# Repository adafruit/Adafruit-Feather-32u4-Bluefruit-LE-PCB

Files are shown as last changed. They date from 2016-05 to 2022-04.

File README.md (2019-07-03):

## Adafruit Feather 32u4 Bluefruit LE PCB

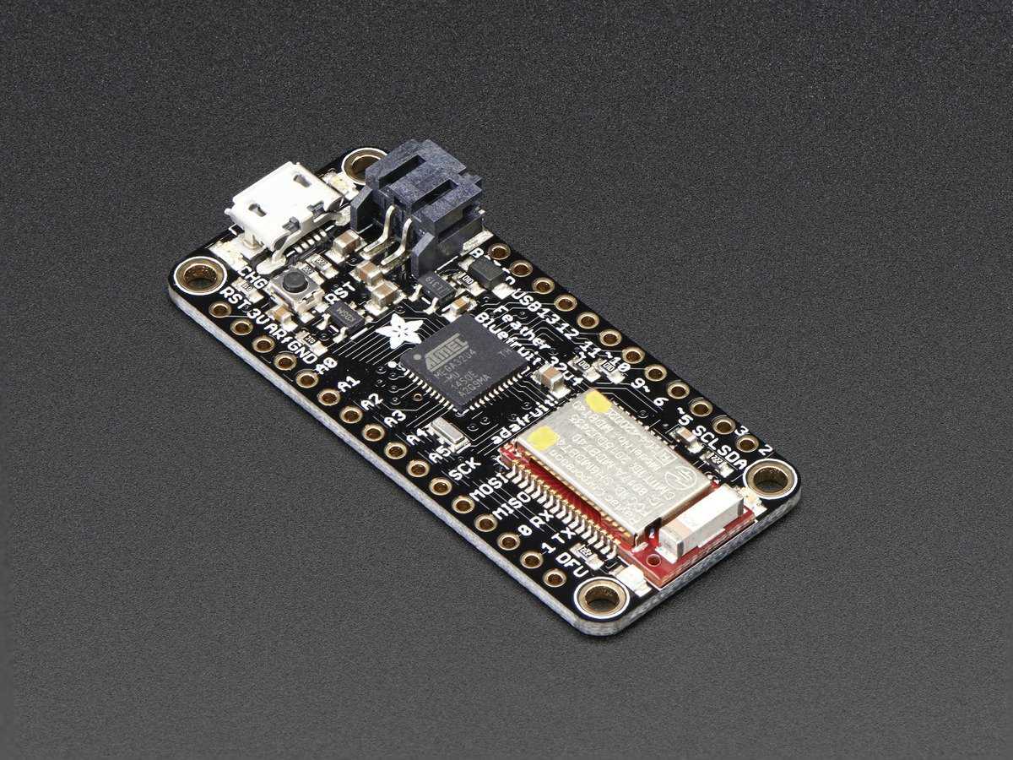
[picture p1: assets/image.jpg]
<a href="http://www.adafruit.com/products/2829"><br/>
Click here to purchase one from the Adafruit shop</a>

PCB files for the Adafruit Feather 32u4 Bluefruit LE. Format is EagleCAD schematic and board layout

For more details, check out the product page at
* https://www.adafruit.com/product/2829

### Description

Feather is the new development board from Adafruit, and like its namesake it is thin, light, and lets you fly! We designed Feather to be a new standard for portable microcontroller cores.

This is the Adafruit Feather 32u4 Bluefruit - our take on an 'all-in-one' Arduino-compatible + Bluetooth Low Energy with built in USB and battery charging. Its an Adafruit Feather 32u4 with a BTLE module, ready to rock! We have other boards in the Feather family, check'em out here.

Bluetooth Low Energy is the hottest new low-power, 2.4GHz spectrum wireless protocol. In particular, its the only wireless protocol that you can use with iOS without needing special certification and it's supported by all modern smart phones. This makes it excellent for use in portable projects that will make use of an iOS or Android phone or tablet. It also is supported in Mac OS X and Windows 8+.

[We have quite a few BTLE-capable Feathers (it's a popular protocol!) so check out our BT Feather guide for some comparison information](https://learn.adafruit.com/adafruit-feather/bluetooth-feathers).

At the Feather 32u4's heart is at ATmega32u4 clocked at 8 MHz and at 3.3V logic, a chip setup we've had tons of experience with as it's the same as the Flora. This chip has 32K of flash and 2K of RAM, with built in USB so not only does it have a USB-to-Serial program & debug capability built in with no need for an FTDI-like chip, it can also act like a mouse, keyboard, USB MIDI device, etc.

To make it easy to use for portable projects, we added a connector for any of our 3.7V Lithium polymer batteries and built in battery charging. You don't need a battery, it will run just fine straight from the micro USB connector. But, if you do have a battery, you can take it on the go, then plug in the USB to recharge. The Feather will automatically switch over to USB power when its available. We also tied the battery thru a divider to an analog pin, so you can measure and monitor the battery voltage to detect when you need a recharge.

### License

Adafruit invests time and resources providing this open source design, please support Adafruit and open-source hardware by purchasing products from [Adafruit](https://www.adafruit.com)!

Designed by Limor Fried/Ladyada for Adafruit Industries.

Creative Commons Attribution/Share-Alike, all text above must be included in any redistribution. See license.txt for additional details.

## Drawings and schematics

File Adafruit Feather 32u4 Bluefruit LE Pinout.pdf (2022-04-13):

# Adafruit Feather 32u4 Bluefruit

# https://www.adafruit.com/products/2829

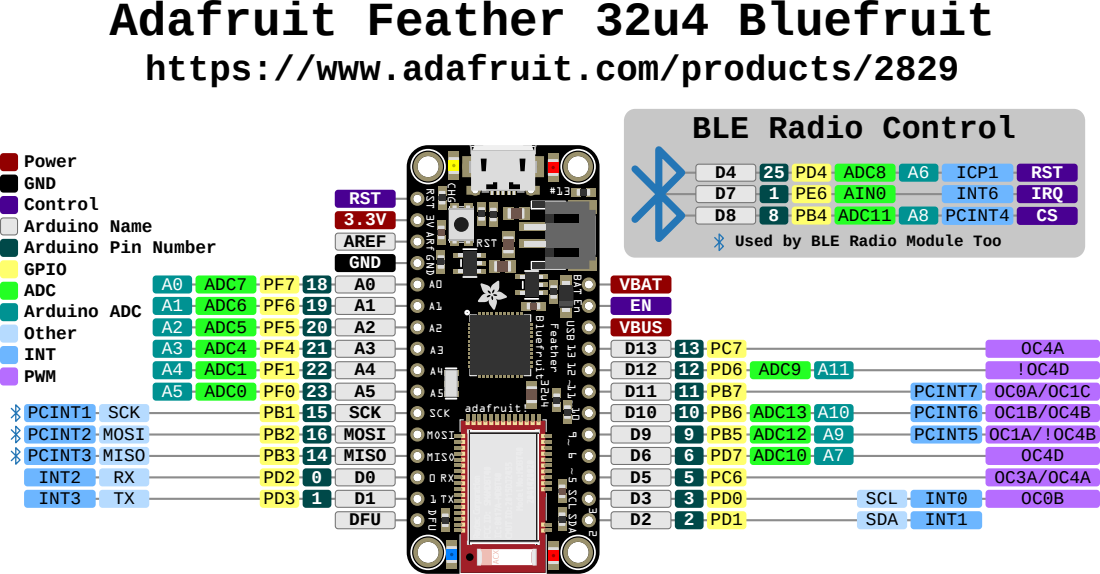
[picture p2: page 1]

Used by BLE Radio Module Too

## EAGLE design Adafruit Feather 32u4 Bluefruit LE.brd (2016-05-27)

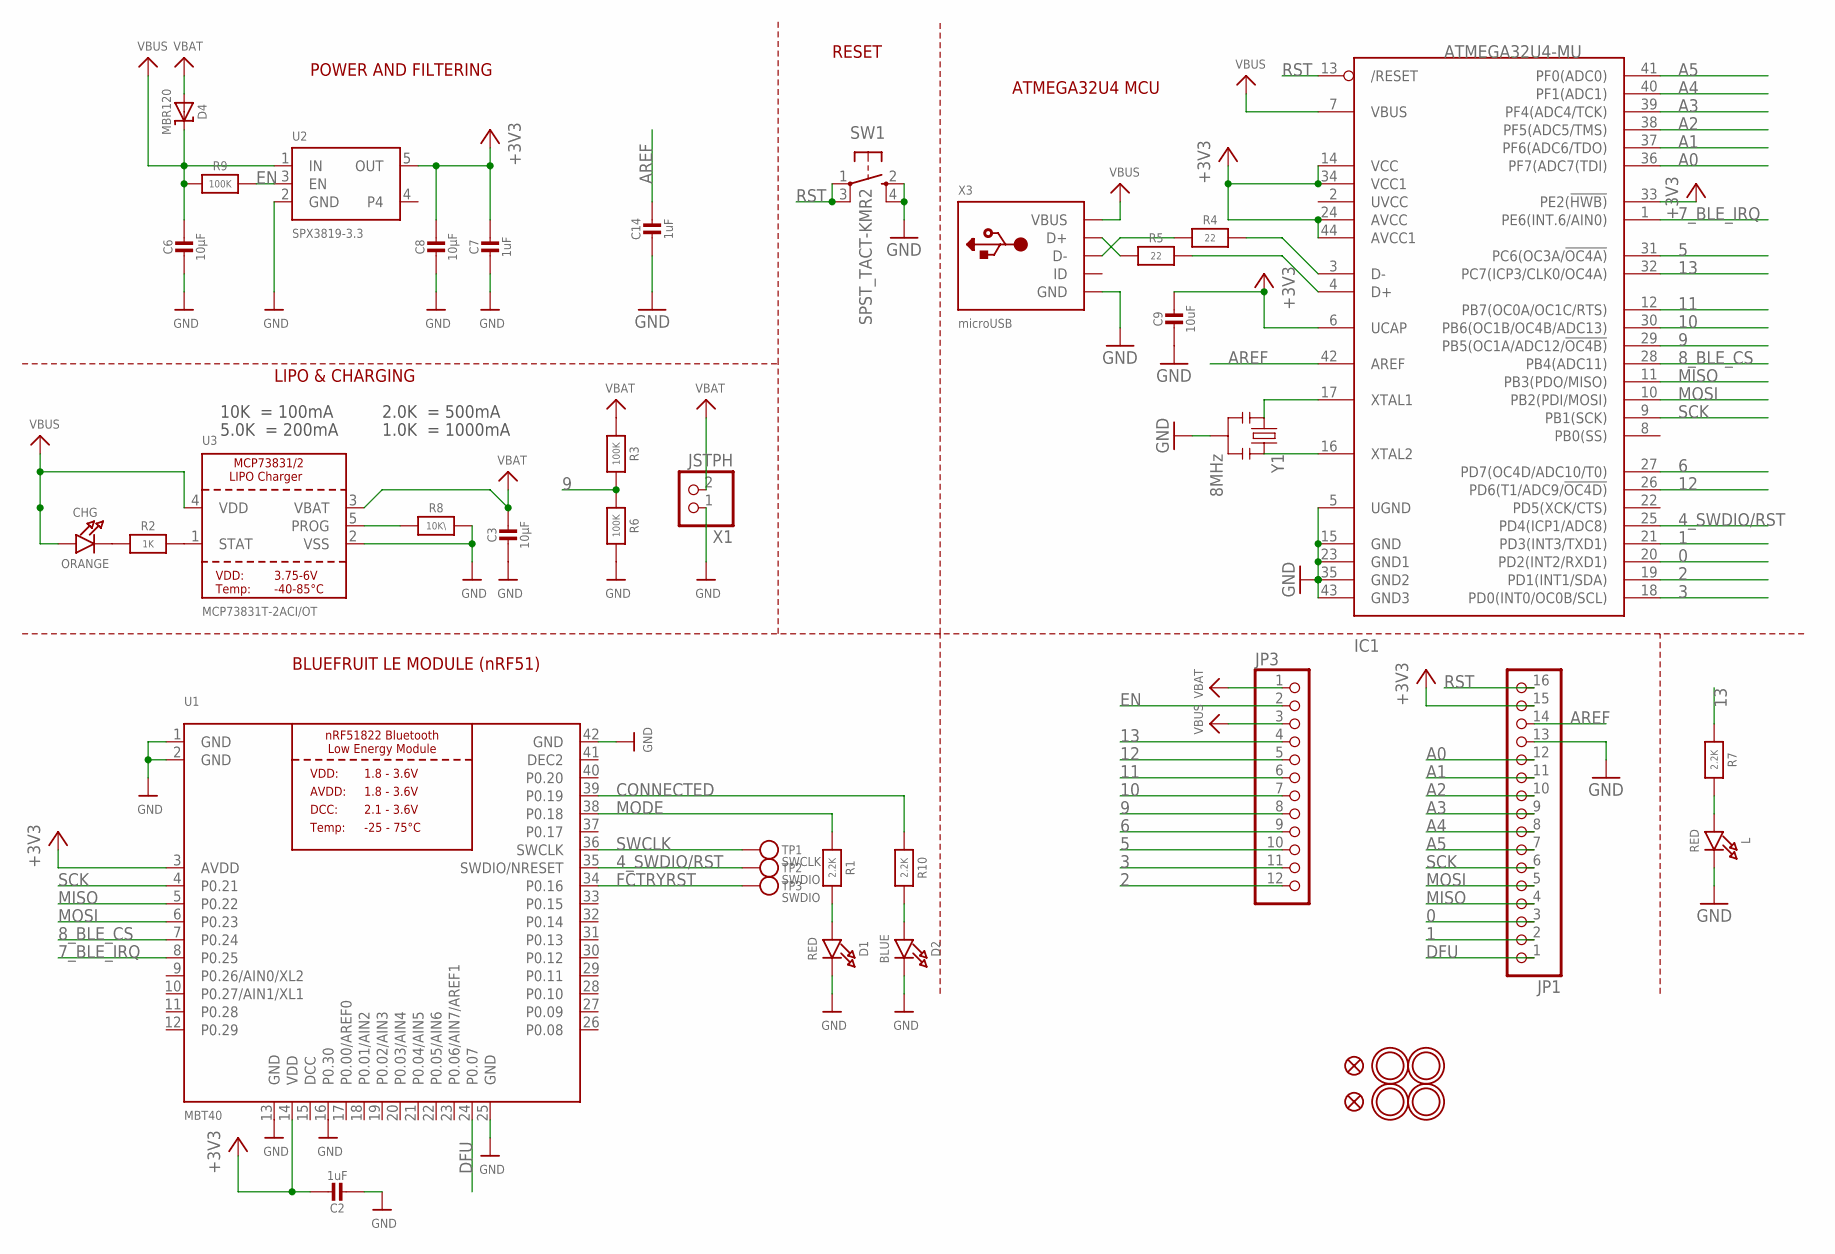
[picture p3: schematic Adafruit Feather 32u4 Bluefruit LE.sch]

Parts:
C2, C7, C14: 1uF; 0603-NO
C3, C6, C8: 10µF; 0805-NO
C9: 10uF; _0805MP
CHG: ORANGE; CHIPLED_0805_NOOUTLINE
D1: RED; CHIPLED_0805_NOOUTLINE
D2: BLUE; CHIPLED_0805_NOOUTLINE
D4: MBR120; SOD-123
IC1: ATMEGA32U4-MU; TQFN44_7MM
JP1: HEADER-1X16ROUND; 1X16_ROUND
JP3: HEADER-1X12; 1X12_ROUND
L: RED; CHIPLED_0805_NOOUTLINE
R1, R7, R10: 2.2K; 0603-NO
R2: 1K; 0603-NO
R3, R6, R9: 100K; 0603-NO
R4, R5: 22; 0603-NO
R8: 10K\; 0603-NO
SW1: SPST_TACT-KMR2; KMR2
TP1: SWCLK; PAD-1.5X2.0
TP2, TP3: SWDIO; PAD-1.5X2.0
U1: MBT40; BLE_MODULE_RAYTAC_MDBT40
U2: SPX3819-3.3; SOT23-5
U3: MCP73831T-2ACI/OT; SOT23-5
U$6, U$24, U$31, U$32: MOUNTINGHOLE2.5; MOUNTINGHOLE_2.5_PLATED
U$34, U$35: FIDUCIAL""; FIDUCIAL_1MM
X1: JSTPH; JSTPH2
X3: microUSB; 4UCONN_20329_V2
Y1: 8MHz; RESONATOR-SMD

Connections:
0: IC1.20 (PD2(INT2/RXD1)), JP1.3
1: IC1.21 (PD3(INT3/TXD1)), JP1.2
2: IC1.19 (PD1(INT1/SDA)), JP3.12
3: IC1.18 (PD0(INT0/OC0B/SCL)), JP3.11
4_SWDIO/RST: IC1.25 (PD4(ICP1/ADC8)), TP2.P$1, U1.35 (SWDIO/NRESET)
5: IC1.31 (PC6(OC3A/!OC4A)), JP3.10
6: IC1.27 (PD7(OC4D/ADC10/T0)), JP3.9
7_BLE_IRQ: IC1.1 (PE6(INT.6/AIN0)), U1.8 (P0.25)
8_BLE_CS: IC1.28 (PB4(ADC11)), U1.7 (P0.24)
9: IC1.29 (PB5(OC1A/ADC12/!OC4B)), JP3.8, R3.2, R6.1
10: IC1.30 (PB6(OC1B/OC4B/ADC13)), JP3.7
11: IC1.12 (PB7(OC0A/OC1C/RTS)), JP3.6
12: IC1.26 (PD6(T1/ADC9/!OC4D)), JP3.5
13: IC1.32 (PC7(ICP3/CLK0/OC4A)), JP3.4, R7.1
+3V3: C2.1, C7.1, C8.1, C9.1, IC1.6 (UCAP), IC1.14 (VCC), IC1.24 (AVCC), IC1.33 (PE2(!HWB)), IC1.34 (VCC1), IC1.44 (AVCC1), JP1.15, U1.3 (AVDD), U1.14 (VDD), U2.5 (OUT)
A0: IC1.36 (PF7(ADC7(TDI)), JP1.12
A1: IC1.37 (PF6(ADC6/TDO)), JP1.11
A2: IC1.38 (PF5(ADC5/TMS)), JP1.10
A3: IC1.39 (PF4(ADC4/TCK)), JP1.9
A4: IC1.40 (PF1(ADC1)), JP1.8
A5: IC1.41 (PF0(ADC0)), JP1.7
AREF: C14.1, IC1.42 (AREF), JP1.14
CONNECTED: R10.1, U1.39 (P0.19)
D+: IC1.4 (D+), R5.2
D-: IC1.3 (D-), R4.2
DCC: U1.15 (DCC)
DEC2: U1.41 (DEC2)
DFU: JP1.1, U1.24 (P0.07)
EN: JP3.2, R9.2, U2.3 (EN)
FCTRYRST: TP3.P$1, U1.34 (P0.16)
GND: C2.2, C3.2, C6.2, C7.2, C8.2, C9.2, C14.2, D1.C, D2.C, IC1.5 (UGND), IC1.15 (GND), IC1.23 (GND1), IC1.35 (GND2), IC1.43 (GND3), JP1.13, L.C, R6.2, R8.2, SW1.2 (S), SW1.4 (S1), U1.1 (GND), U1.2 (GND), U1.13 (GND), U1.16 (P0.30), U1.25 (GND), U1.42 (GND), U2.2 (GND), U3.2 (VSS), X1.1, X3.BASE@1 (GND), X3.BASE@2 (GND), X3.GND, X3.SPRT@1 (GND), X3.SPRT@2 (GND), X3.SPRT@3 (GND), X3.SPRT@4 (GND), Y1.2
MISO: IC1.11 (PB3(PDO/MISO)), JP1.4, U1.5 (P0.22)
MODE: R1.1, U1.38 (P0.18)
MOSI: IC1.10 (PB2(PDI/MOSI)), JP1.5, U1.6 (P0.23)
unnamed: CHG.C, R2.1
unnamed: L.A, R7.2
unnamed: R2.2, U3.1 (STAT)
unnamed: R8.1, U3.5 (PROG)
unnamed: D1.A, R1.2
unnamed: D2.A, R10.2
unnamed: IC1.16 (XTAL2), Y1.3
unnamed: IC1.17 (XTAL1), Y1.1
unnamed: R5.1, X3.D+
unnamed: R4.1, X3.D-
RST: IC1.13 (/RESET), JP1.16, SW1.1, SW1.3 (P1)
SCK: IC1.9 (PB1(SCK)), JP1.6, U1.4 (P0.21)
SWCLK: TP1.P$1, U1.36 (SWCLK)
VBAT: C3.1, D4.A, JP3.1, R3.1, U3.3 (VBAT), X1.2
VBUS: C6.1, CHG.A, D4.C, IC1.7 (VBUS), JP3.3, R9.1, U2.1 (IN), U3.4 (VDD), X3.VBUS

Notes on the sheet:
POWER AND FILTERING
BLUEFRUIT LE MODULE (nRF51)
RESET
ATMEGA32U4 MCU
10K = 100mA
5.0K = 200mA
2.0K = 500mA
1.0K = 1000mA
LIPO & CHARGING

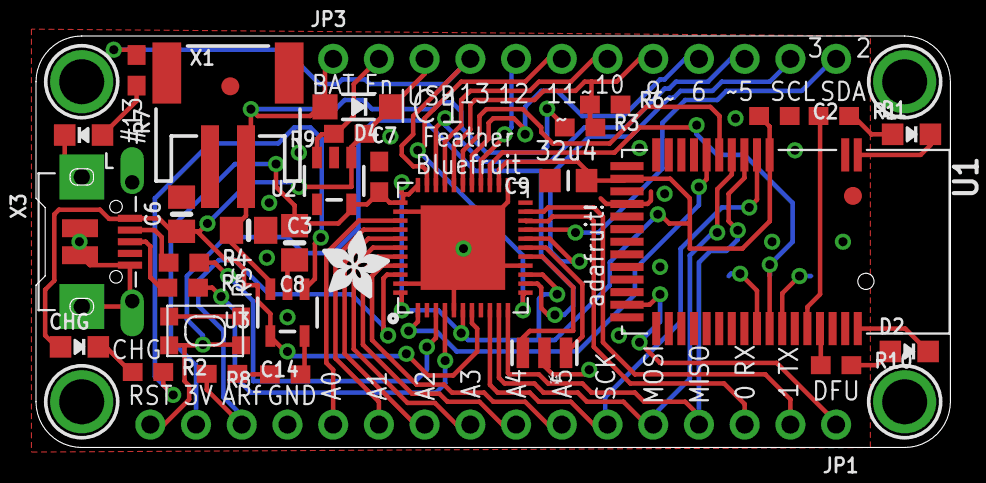
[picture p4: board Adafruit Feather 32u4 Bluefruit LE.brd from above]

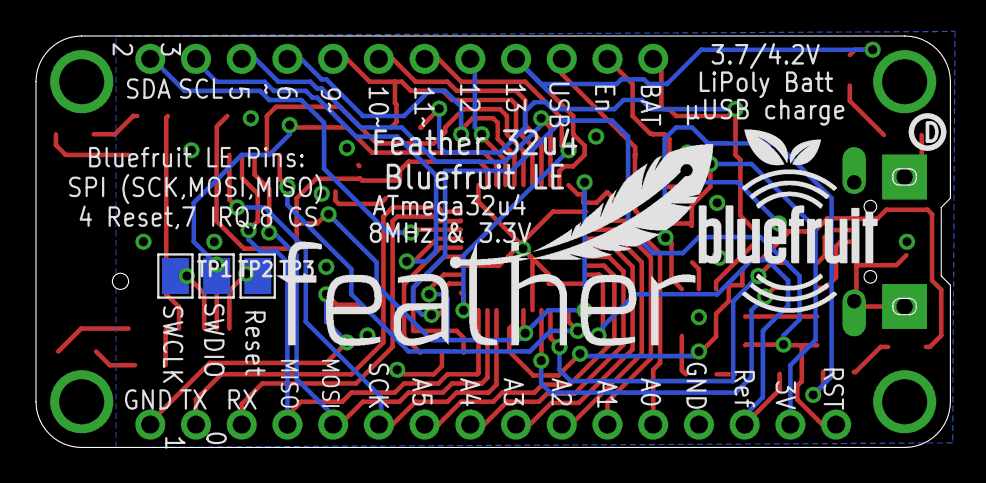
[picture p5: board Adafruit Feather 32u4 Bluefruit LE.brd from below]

Board: 2 copper layers, 50.8 x 22.9 mm, 45 parts (6 on the bottom side), 47 nets.

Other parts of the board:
U$7: ADAFRUIT_3.5MM
U$9: FEATHERLOGO
U$23: PCBFEAT-REV-040
U$26: BLUEFRUITLOGO_100MM

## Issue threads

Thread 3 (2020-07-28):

.sch file not recognized

benlcohn, 2020-07-28:
Hi there,

I am unable to open either file in KiCad for whatever reason.  Unknown error for the PCB, and the .sch file is giving an error that the file 'does not appear to be an Eeschema file'.

Any help would be most appreciated.

ladyada, 2020-07-28:
its eaglecad

Closed 2020-07-28.

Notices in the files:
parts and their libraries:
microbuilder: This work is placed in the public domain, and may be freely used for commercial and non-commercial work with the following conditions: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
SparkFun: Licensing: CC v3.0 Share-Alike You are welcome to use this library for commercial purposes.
